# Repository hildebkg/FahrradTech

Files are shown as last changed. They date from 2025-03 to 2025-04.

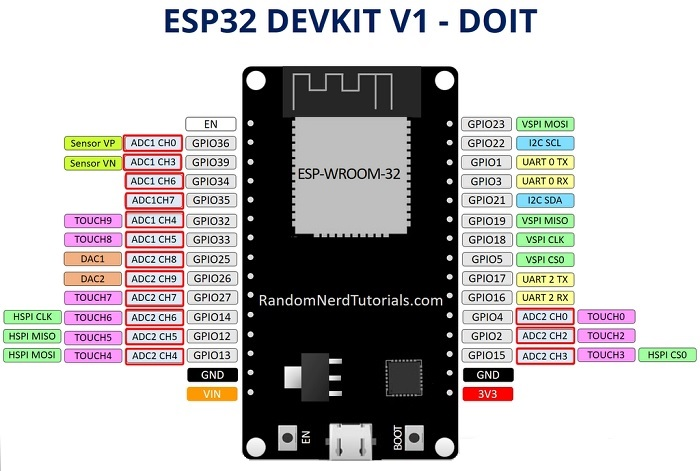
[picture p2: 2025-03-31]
references/esp32_devkitv1_pinout.png

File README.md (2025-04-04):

# FahrradTech

Senior design project files for FahrradTech: an affordable, feature-rich bike computer with integrated safety accessories.

## Navigation

* [/img](/img): project images (referenced throughout this repo)
* [/main](/main): project source code
* [/managed_components](/managed_components/): project libraries
* [/references](/references/): datasheets, etc
* [/schematics](/schematics/): hardware design files
* [/sim](/sim): hardware simulation files

## Getting Started

This project utilizes the official Espressif Systems IoT Development Framework (ESP-IDF). You can view Espressif's official getting started docs [here](https://docs.espressif.com/projects/esp-idf/en/stable/esp32/get-started/index.html). I did a manual installation on Windows 10 (more info on that specifically [here](https://docs.espressif.com/projects/esp-idf/en/stable/esp32/get-started/windows-setup.html)).

* Download the proper installer for your machine (I used “Universal Online Installer 2.3.4” for Windows 10) and run it.
  * I mostly ran with default settings, but I did check the box to install the IDE in case I ever wanted to use it.
* After installation is complete, open a command prompt and run the following commands:
  * `cd C:\Espressif\frameworks\esp-idf-v5.4` (or whatever your install directory is)
  * `install.bat`
    * This installs the ESP-IDF Python virtual environment.
  * `export.bat`
    * This adds ESP-IDF Tools to PATH (not required).
* Keep things simple and get a demo project from [here](https://github.com/espressif/esp-idf/tree/v5.2.5/examples/get-started) or from your install directory (in \examples\get-started). Copy the entire folder to your desired workspace.
* Download the required serial drivers for your board.
  * My board contains a CP2102 USB to UART bridge, but others may differ. If yours has a CP2102, you can download the drivers from Silicon Labs [here](https://www.silabs.com/developer-tools/usb-to-uart-bridge-vcp-drivers?tab=downloads).
* Connect your ESP32 device to your machine and take note of the port to which it is connected. You will need this for the next step. On Windows, this can be checked via the Device Manager.
* To test your chosen example project, fire up either ESP-IDF Cmd or ESP-IDF PowerShell and run the following commands:
  * `cd <dir_containing_example_project>`
  * `idf.py add-dependency esp32`
    * This adds the Board Support Package (BSP) for ESP32 boards. If you have something specific, you can look for it in the [IDF Component Registry](https://components.espressif.com/).
  * `idf.py build`
    * This builds the project. This will take a bit the first time!
  * `idf.py – p COM# flash`
    * This flashes your device with the most recent build.
    * Make sure to replace "COM#" with the port your device is currently using.
  * `idf.py -p COM# monitor`
    * This relays serial data to and from your target device's serial port. This allows you to see output from your board after it has been flashed.
    * More information [here](https://docs.espressif.com/projects/esp-idf/en/stable/esp32/api-guides/tools/idf-monitor.html).
* To add extra components to your project (from within ESP-IDF CMD or PowerShell):
  * `cd <dir_containing_example_project>`
  * `idf.py add-dependency "component_name"`
    * You should replace "component_name" with the name contained in the [IDF Component Registry](https://components.espressif.com/).
  * `idf.py reconfigure`
    * Processes the `idf_component.yml` file in your `main` folder for each component in your project and resolves dependencies.
    * Creates/updates the `dependencies.lock` file in your  project directory with the full dependency list.
    * Downloads all newly-added depedencies to the `managed_components` folder in your project directory.
* If you want to remove a component you have added, you can simply edit the `/main/idf_component.yml` directly. For example, if you added the `espressif/esp_lcd_st7796` component but no longer want it, you can remove that corresponding line in your YAML file and then run `idf.py reconfigure`. You will get a message similar to "NOTICE: Deleting 1 unused components", and the component will be removed for you. Your `dependencies.lock` file will also be updated.
* If you'd like to make development easier in Visual Studio Code with the C/C++ extension, you should add the following to the "include path" setting for the extension: `C:/Espressif/frameworks/esp-idf-v5.4/components/**` (or whatever your specific path is). This will make it so that VS Code can find standard ESP header files that aren't necessarily in your `managed_components folder`.

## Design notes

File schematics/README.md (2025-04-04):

# Hardware Design Files

Schematics and PCB layouts for this project were created in KiCad 8.0.

For convenience, you can view a PDF of each schematic below:

* [Bike computer](bike_computer/bike_computer.pdf)
* [Rear lights unit](rear_lights_unit/rear_lights_unit.pdf)
* [Rear lights unit control box](rear_lights_unit_control_box/rear_lights_unit_control_box.pdf)

Other important components:

* [Symbol library file](FahrradTech.kicad_sym)
* [Footprint files](FahrradTech.pretty/)

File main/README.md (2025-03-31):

# Project Source Code

`main.c` is the main project file and is what is typically built and flashed to the ESP32.

Other .c files in this folder are standalone demonstration files for various components considered for/incorporated in the project. If you want to build one of these instead of the main file, you can modify the `CMakeLists.txt` file in this directory. For example, if you wanted to build `sht3x_demo.c`, you can change the `SRCS` parameter given to `idf_component_register` in the CMake file from `main.c` to `sht3x_demo.c`.

**Note!** I tried a few different parts before I settled on the current design, so some of the demo files here are not applicable to the most recent designs. The following is a list of components that are no longer being used. If you would like to try any of these out, just be sure to add the corresponding component to your project (see root README for more info on this). Doing so will download the necessary files into your managed_components directory.

* [SHT3x temp/humidity sensor](https://components.espressif.com/components/espressif/sht3x/versions/0.2.0)
* [BMP280 pressure sensor](https://components.espressif.com/components/maucke/bmp280/versions/1.0.1)
  * Special note on this one: I had to make several changes to this component library to make it work. Please see my previous commit [here](https://github.com/hildebkg/FarrhadTech/commit/3e463adc17b4526ff7c5bdaee2d7144cd09fb9ec) with the changes if needed.

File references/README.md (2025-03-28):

# References

These are various files that I have downloaded from the internet and referenced in some way for this project. I do not own any of these resources.

(links to be updated)

* [BME280 datasheet](https://web.archive.org/web/20250320165039/https://www.bosch-sensortec.com/media/boschsensortec/downloads/datasheets/bst-bme280-ds002.pdf)
* [Samsung 30Q 18650 battery 1](https://web.archive.org/web/20250228134656/https://www.18650batterystore.com/products/samsung-30q)
* [Samsung 30Q 18650 battery 2](https://web.archive.org/web/20231027183936/https://www.joke-technology.com/media/pdf/c4/9a/9b/datenblatt_inr18650-30q6_cell_specification.pdf)
* [Samsung 30Q 18650 battery study](https://web.archive.org/web/20250219034915/https://lygte-info.dk/review/batteries2012/Samsung%20INR18650-30Q%203000mAh%20(Pink)%20UK.html)

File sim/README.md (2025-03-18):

# Simulation Files

Simulation files for this project were created using National Instruments Multisim version 14.3.

* [Turn signal controls](light_control.ms14)

*Note: KiCad does support SPICE simulation, but I have never used it, and I have heard that the learning curve is steep. I am already used to using Multisim through my university, so I chose to use that for now. There is a free online version which can be accessed [here](https://www.multisim.com/), but they do not currently support importing .MS14 files, so I have added screenshots to this folder for recreation purposes.*

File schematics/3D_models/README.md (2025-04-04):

# 3D Models

KiCad supports adding your own 3D model files on a per-footprint basis. Most of the models in this project are included in the KiCad standard library. I have temporarily borrowed those that weren't via the links below.

* [BME280 sensor module](https://grabcad.com/library/bme280-model-1)
* [ESP-WROOM-32 DevKitV1](https://grabcad.com/library/esp32_devkitv1-1)
* [TP4056 BMS module](https://grabcad.com/library/tp4056-charging-module-type-c-1)

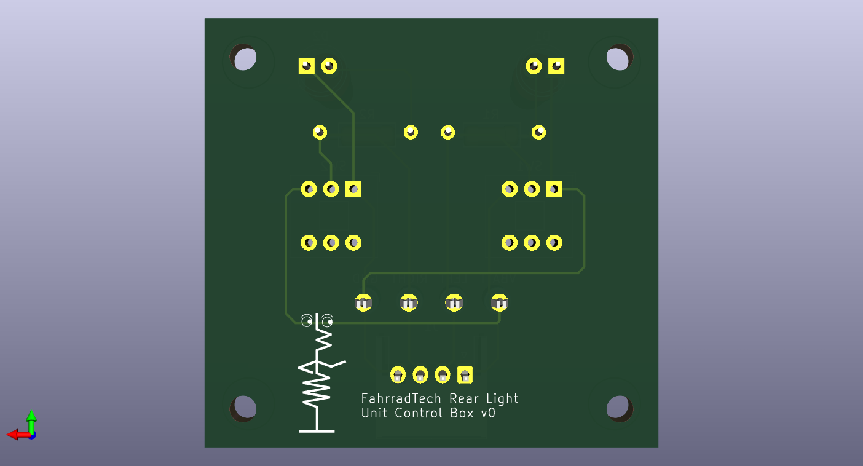
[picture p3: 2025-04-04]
img/rear_lights_unit_control_box_PCB_3D_view_bottom.png

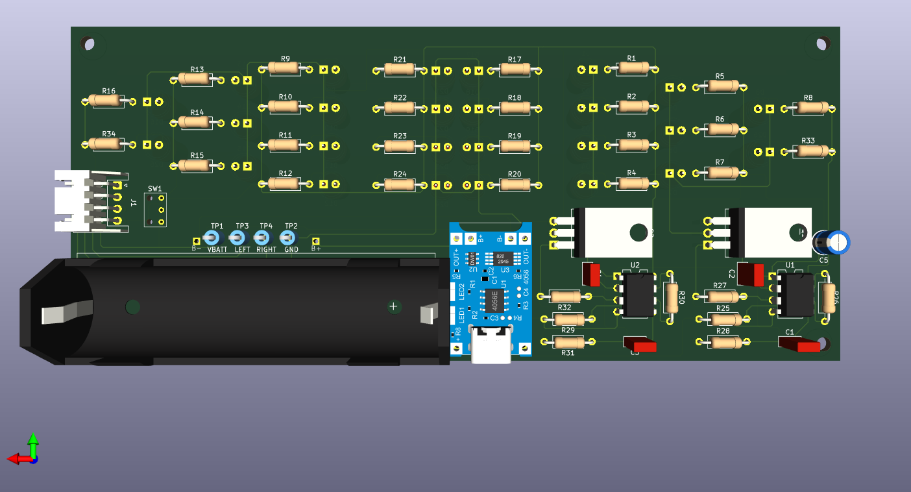
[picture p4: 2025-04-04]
img/rear_lights_unit_PCB_3D_view_bottom.png

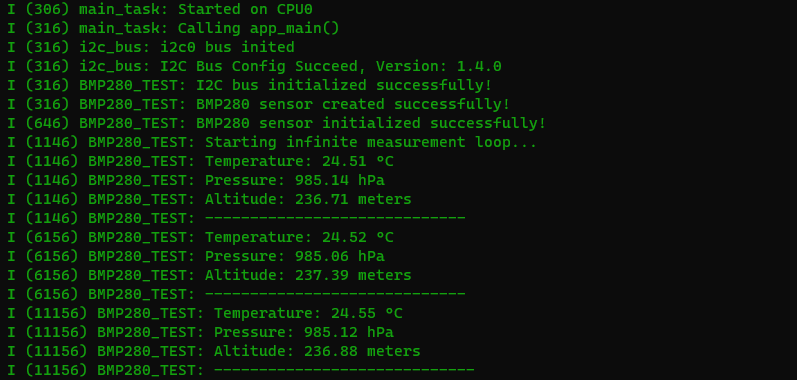
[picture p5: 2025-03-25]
img/BMP_280_demo_sc.png

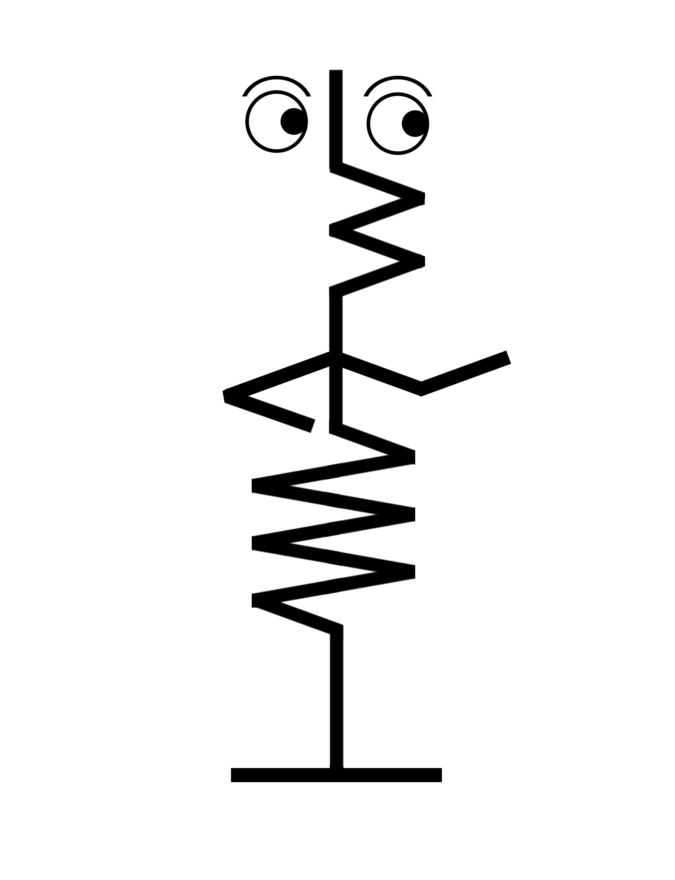
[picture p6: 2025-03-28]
img/RESISTY.png

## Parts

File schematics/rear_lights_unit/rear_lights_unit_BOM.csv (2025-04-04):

Reference | Value | Part Num | Description | Qty | Footprint
BT1 | Battery_Cell | Samsung 30Q 18650 | 18650 battery, 3000 mAH, 3.7 V nominal | 1 | FahrradTech:BatteryHolder_18650
C1,C3 | 0.01uF | K103K15X7RF5TK2 | Unpolarized capacitor, 50 VDC, X7R, 10%, 2.5 mm lead spacing | 2 | Capacitor_THT:C_Rect_L4.6mm_W2.0mm_P2.50mm_MKS02_FKP02
C2,C4 | 10uF | FG18X5R1E106MRT06 | Unpolarized capacitor, 25 VDC, X5R, 20%, 5 mm lead spacing | 2 | Capacitor_THT:C_Rect_L4.6mm_W2.0mm_P2.50mm_MKS02_FKP02
C5 | 10uF | ECA-1EM100 | Polarized capacitor, 25 VDC, 20%, 2mm lead spacing | 1 | Capacitor_THT:CP_Radial_D5.0mm_P2.00mm
D1,D2,D3,D4,D5,D6,D7,D8,D9,D10,D11,D12,D13,D14,D15,D16,D17,D18,D19,D20,D21,D22,D23,D24,D25,D26 | LED | Chanzon LED | Light emitting diode, red or yellow | 26 | LED_THT:LED_D5.0mm
J1 | Conn_01x04_Socket | JST XH-2.54 | Generic connector, single row, 01x04, script generated | 1 | Connector_JST:JST_XH_S4B-XH-A_1x04_P2.50mm_Horizontal
Q1,Q2 | IRLZ44N | IRLZ44N | 47A Id, 55V Vds, 22mOhm Rds Single N-Channel HEXFET Power MOSFET, TO-220AB | 2 | FahrradTech:TO-220-3_Horizontal_TabUpNoHole
R1,R2,R3,R4,R5,R6,R7,R8,R9,R10,R11,R12,R13,R14,R15,R16,R17,R18,R19,R20,R21,R22,R23,R24,R33,R34 | 120 | MFR-25SFTF52-120R | Resistor, 0.25 W, 1% | 26 | Resistor_THT:R_Axial_DIN0207_L6.3mm_D2.5mm_P10.16mm_Horizontal
R25,R29 | 7.5k | MFR-25FTE52-7K5 | Resistor, 0.25 W, 1% | 2 | Resistor_THT:R_Axial_DIN0207_L6.3mm_D2.5mm_P10.16mm_Horizontal
R26,R30 | 75k | MFR-25FTE52-75K | Resistor, 0.25 W, 1% | 2 | Resistor_THT:R_Axial_DIN0207_L6.3mm_D2.5mm_P10.16mm_Horizontal
R27,R32 | 100 | MFR-25SFTF52-100R | Resistor, 0.25 W, 1% | 2 | Resistor_THT:R_Axial_DIN0207_L6.3mm_D2.5mm_P10.16mm_Horizontal
R28,R31 | 10k | MFR-25SFRF52-10K | Resistor, 0.25 W, 1% | 2 | Resistor_THT:R_Axial_DIN0207_L6.3mm_D2.5mm_P10.16mm_Horizontal
SW1 | GW12LxH | GW12LCH | SPDT paddle switch, red, right-angle | 1 | FahrradTech:SW_Lever_1P2T_NKK_GW12LxH
TP1 | VBATT | Keystone Electronics 5000 | Test point loop, red | 1 | FahrradTech:TestPoint_Keystone_5000-5004_Miniature
TP2 | GND | Keystone Electronics 5002 | Test point loop, black | 1 | FahrradTech:TestPoint_Keystone_5000-5004_Miniature
TP3 | LEFT | Keystone Electronics 5001 | Test point loop, white | 1 | FahrradTech:TestPoint_Keystone_5000-5004_Miniature
TP4 | RIGHT | Keystone Electronics 5001 | Test point loop, white | 1 | FahrradTech:TestPoint_Keystone_5000-5004_Miniature
U1,U2 | LMC555xN | LMC555CN/NOPB | CMOS Timer, 555 compatible, PDIP-8 | 2 | Package_DIP:DIP-8_W7.62mm
U3 | TP4056 module | TP4056 module | 18650 battery management module | 1 | FahrradTech:TP4056_module

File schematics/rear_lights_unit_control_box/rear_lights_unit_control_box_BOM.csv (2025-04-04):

Reference | Value | Part Num | Description | Qty | Footprint
D1,D2 | LED | CHANZON 5mm LED | Light emitting diode, yellow | 2 | LED_THT:LED_D5.0mm
J1 | Conn_01x04_Socket | JST XH-2.54 | 01x04 pin JST right-angle connector | 1 | Connector_JST:JST_XH_S4B-XH-A-1_1x04_P2.50mm_Horizontal
R1,R2 | 120 | MFR-25SFTF52-120R | Resistor, 0.25 W, 1% | 2 | Resistor_THT:R_Axial_DIN0207_L6.3mm_D2.5mm_P10.16mm_Horizontal
SW1,SW2 | SW_SPDT | SPDT SW | Switch, single pole double throw | 2 | Button_Switch_THT:SW_Push_2P2T_Toggle_CK_PVA2xxH2xxxxxxV2
TP1 | VBATT | Keystone Electronics 5000 | Test point loop, red | 1 | FahrradTech:TestPoint_Keystone_5000-5004_Miniature
TP2 | LEFT | Keystone Electronics 5001 | Test point loop, white | 1 | FahrradTech:TestPoint_Keystone_5000-5004_Miniature
TP3 | RIGHT | Keystone Electronics 5001 | Test point loop, white | 1 | FahrradTech:TestPoint_Keystone_5000-5004_Miniature
TP4 | GND | Keystone Electronics 5002 | Test point loop, black | 1 | FahrradTech:TestPoint_Keystone_5000-5004_Miniature

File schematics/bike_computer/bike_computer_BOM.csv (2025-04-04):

Reference | Value | Part Num | Description | Qty | Footprint
BT1 | Battery_Cell | Samsung 30Q 18650 | 18650 battery, 3000 mAH, 3.7 V nominal | 1 | FarrhadTech:BatteryHolder_18650
C1,C4,C5,C6 | 0.1uF | FG18X7R1H104KNT00 | Unpolarized capacitor, 50 VDC, X7R, 10%, 2.5 mm lead spacing | 4 | Capacitor_THT:C_Rect_L4.6mm_W2.0mm_P2.50mm_MKS02_FKP02
C2 | 470pF | K471K15X7RF53L2 | Unpolarized capacitor, 50 VDC, X7R, 10%, 2.5 mm lead spacing | 1 | Capacitor_THT:C_Rect_L4.6mm_W2.0mm_P2.50mm_MKS02_FKP02
C3,C7 | 10uF | ECA-1EM100 | Polarized capacitor, 25 VDC, 20%, 2mm lead spacing | 2 | Capacitor_THT:CP_Radial_D5.0mm_P2.00mm
R1 | 121k | MFR-25FBF52-121K | Resistor, 0.25 W, 1% | 1 | Resistor_THT:R_Axial_DIN0207_L6.3mm_D2.5mm_P10.16mm_Horizontal
R2 | 40.2k | MFR-25FTE52-40K2 | Resistor, 0.25 W, 1% | 1 | Resistor_THT:R_Axial_DIN0207_L6.3mm_D2.5mm_P10.16mm_Horizontal
SW1 | GW12LxH | GW12LxH | SPDT paddle switch, red, right-angle | 1 | FarrhadTech:SW_Lever_1P2T_NKK_GW12LxH
TP1 | VBATT | Keystone Electronics 5000 | Test point loop, red | 1 | FarrhadTech:TestPoint_Keystone_5000-5004_Miniature
TP2 | GND | Keystone Electronics 5002 | Test point loop, black | 1 | FarrhadTech:TestPoint_Keystone_5000-5004_Miniature
TP3 | 3V3 | Keystone Electronics 5000 | Test point loop, red | 1 | FarrhadTech:TestPoint_Keystone_5000-5004_Miniature
U2 | BME280 | BME280 module | 3-in-1 sensor, humidity, pressure, temperature, I2C and SPI interface, 1.71-3.6V | 1 | FarrhadTech:BME280_module
U3 | TC1263 | TC1263-3.3VAT | 3.3 V Fixed-Output CMOS LDO | 1 | FarrhadTech:TO-220-5_P3.4x3.8mm_StaggerOdd_Lead7.13mm_TabDown
U4 | TFT LCD ST7796 | Hosyond TFT LCD 480x320 | 480x320 TFT Touch Screen LCD | 1 | FarrhadTech:Display_420x380
U5 | TP4056 module | TP4056 module | 18650 battery management module | 1 | FarrhadTech:TP4056_module
U6 | RYS352A | REYAX RYS352A | UART GNSS antenna module | 1 | FarrhadTech:RYS352A
U7 | ESP-WROOM-32-DevKitV1 | ESP-WROOM-32-DevKitV1 | RF Module, ESP32-D0WDQ6 SoC, Wi-Fi 802.11b/g/n, Bluetooth, BLE, 32-bit, 2.7-3.6V, onboard antenna, SMD | 1 | FarrhadTech:ESP-WROOM-32_DevKitV1

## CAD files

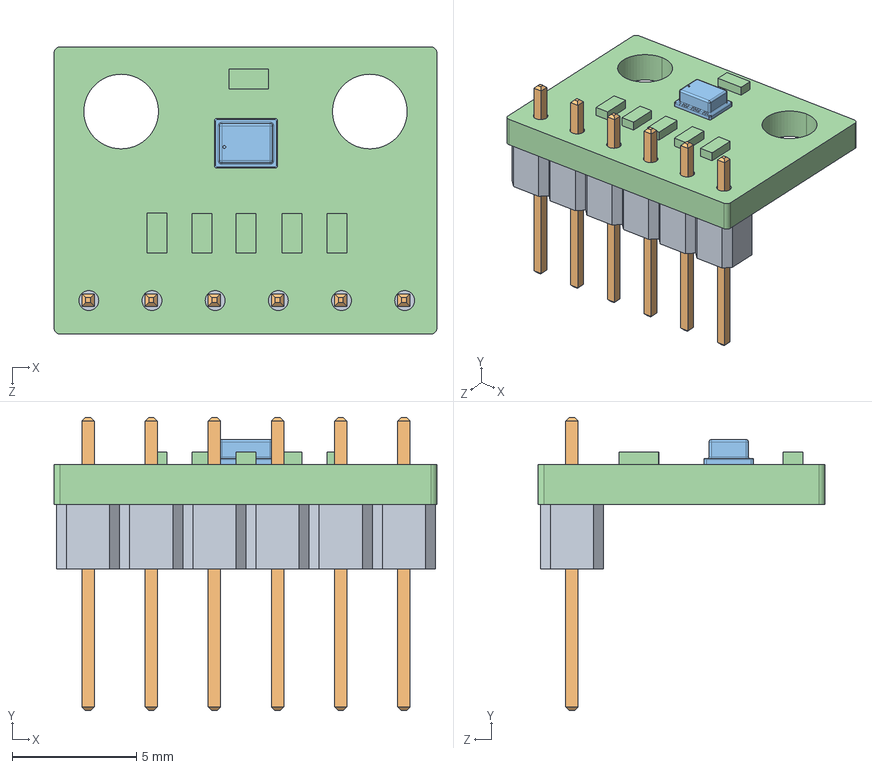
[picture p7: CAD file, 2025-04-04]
schematics/3D_models/BME280_SENSOR_MODULE_WITH_HEADER.STEP
15.4 x 11.8 x 11.6 mm

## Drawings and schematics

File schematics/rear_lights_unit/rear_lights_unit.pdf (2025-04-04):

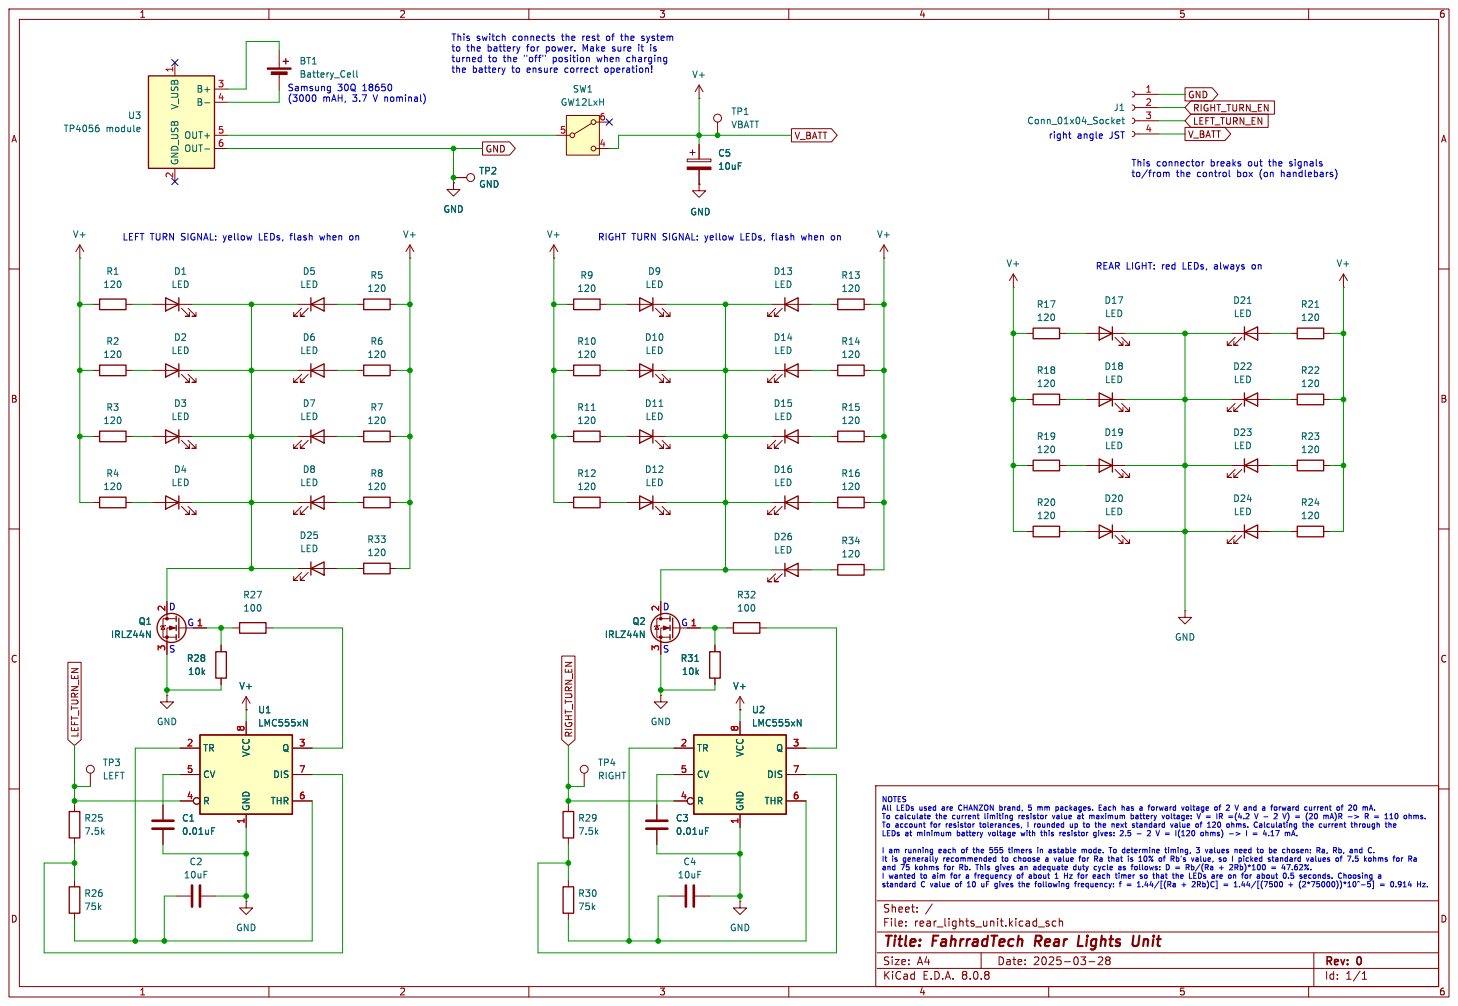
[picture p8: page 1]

to the battery for power. Make sure it is

the battery to ensure correct operation! G

right angle JST Samsung 30Q 18650

RIGHT TURN SIGNAL: yellow LEDs, flash when on D

Id: 1/1 Title: FahrradTech Rear Lights Unit File: rear_lights_unit.kicad_sch Sheet: /

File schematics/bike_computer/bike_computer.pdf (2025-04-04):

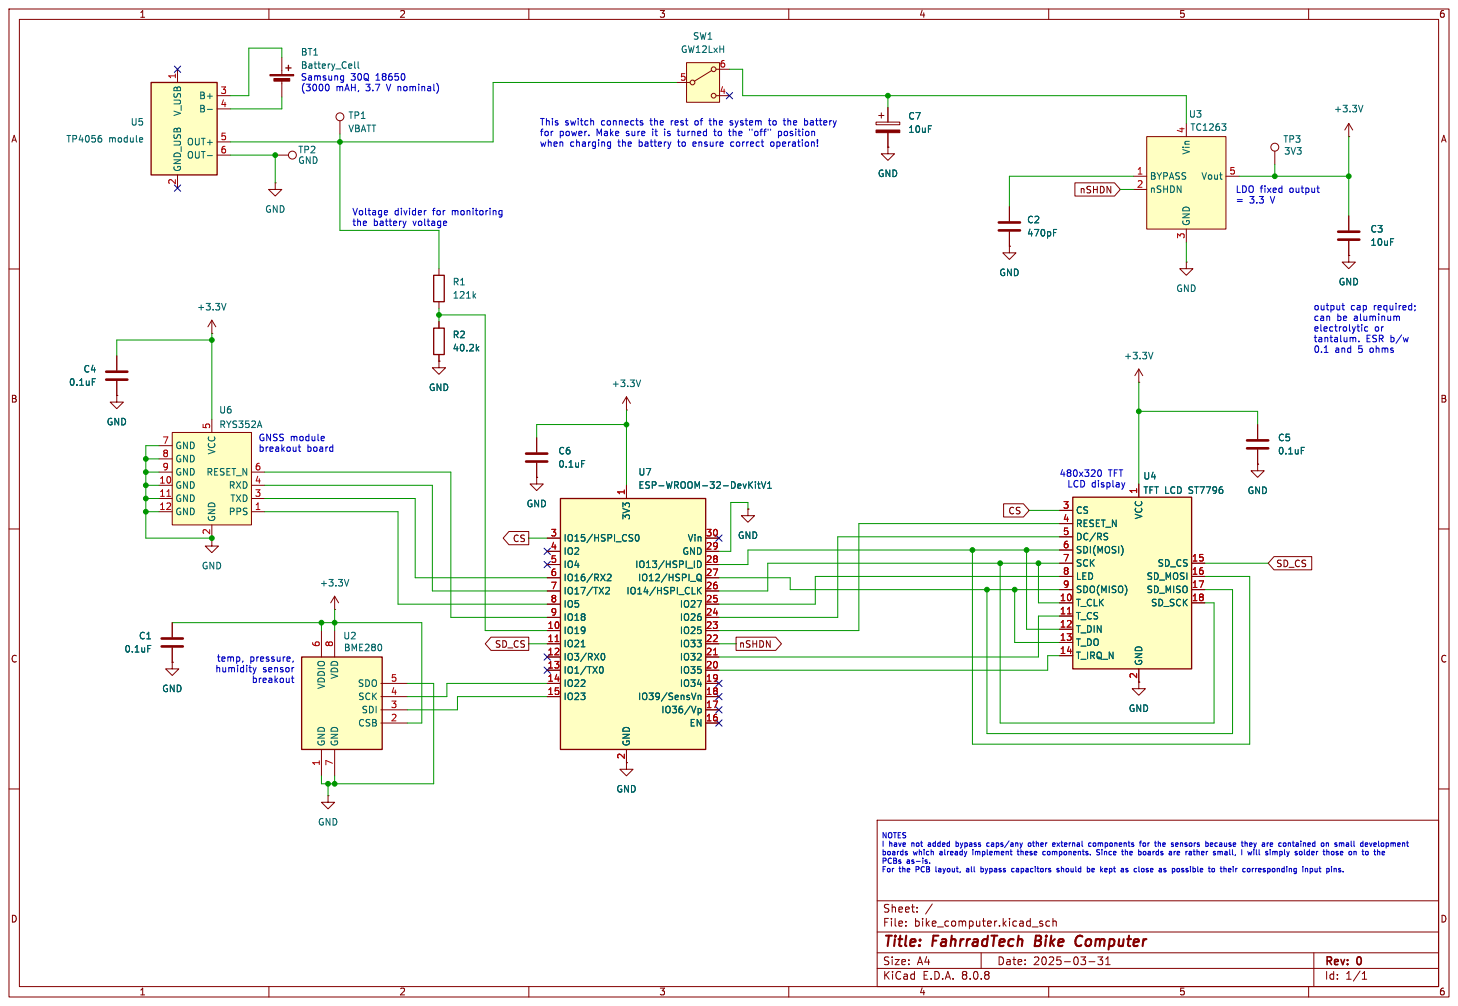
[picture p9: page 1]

1 GND_USB
Id: 1/1 Title: FahrradTech Bike Computer File: bike_computer.kicad_sch Sheet: / V_USB

2 B+ 3 B- 4 OUT+ 5 OUT- 6 U5 TP4056 module GND

0.1 and 5 ohms LDO fixed output = 3.3 V

Voltage divider for monitoring
the battery voltage

output cap required; can be aluminum

2 CS 3 RESET_N 4 DC/RS 5 SDI(MOSI) 6 SCK 7

1 CSB 2 SDI 3 SCK 4 SDO 5 VDDIO

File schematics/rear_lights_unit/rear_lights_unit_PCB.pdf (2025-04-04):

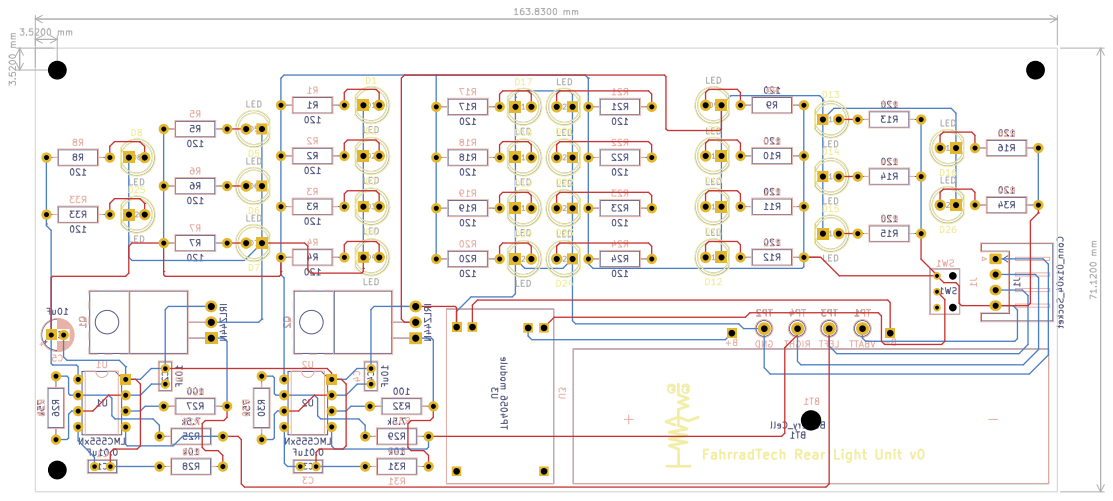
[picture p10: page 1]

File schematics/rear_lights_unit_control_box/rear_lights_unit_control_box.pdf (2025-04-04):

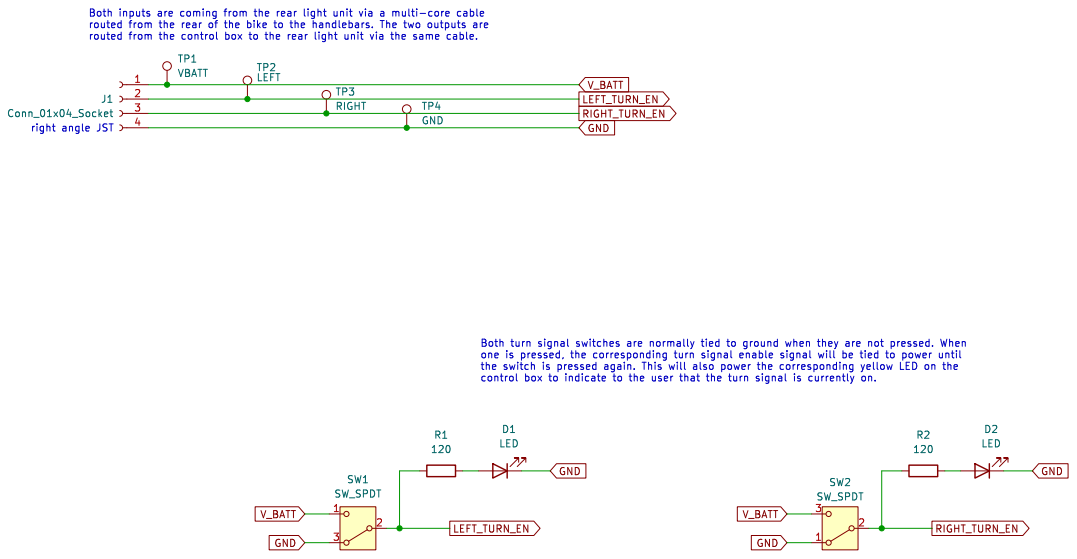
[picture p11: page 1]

Id: 1/1 Title: FahrradTech Rear Lights Unit Control Box

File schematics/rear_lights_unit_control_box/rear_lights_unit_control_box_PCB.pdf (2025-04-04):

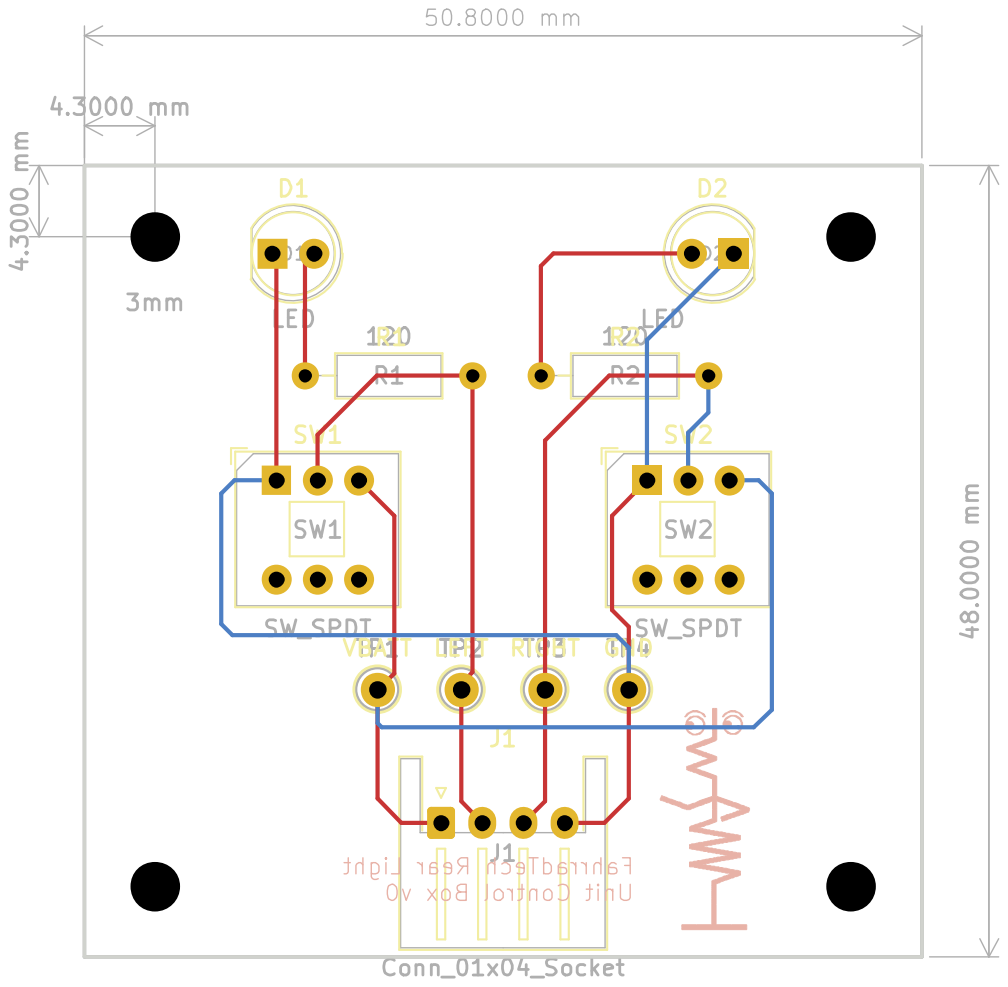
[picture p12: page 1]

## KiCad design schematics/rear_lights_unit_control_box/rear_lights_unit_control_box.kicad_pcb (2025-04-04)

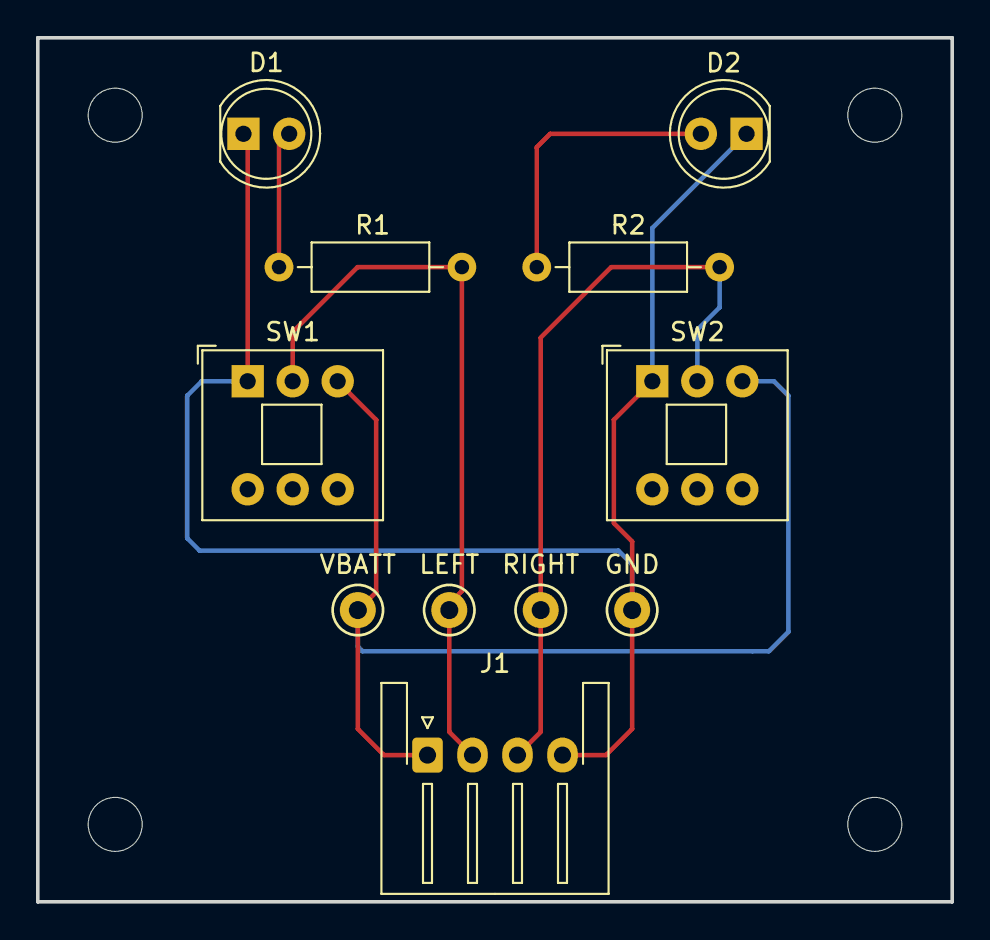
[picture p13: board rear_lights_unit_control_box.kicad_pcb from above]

Board: 2 copper layers, 50.8 x 48.0 mm, 11 parts (0 on the bottom side), 6 nets.

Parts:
D1, D2: LED; LED_D5.0mm
J1: Conn_01x04_Socket; JST_XH_S4B-XH-A-1_1x04_P2.50mm_Horizontal
R1, R2: 120; R_Axial_DIN0207_L6.3mm_D2.5mm_P10.16mm_Horizontal
SW1, SW2: SW_SPDT; SW_Push_2P2T_Toggle_CK_PVA2xxH2xxxxxxV2
TP1: VBATT; TestPoint_Keystone_5000-5004_Miniature
TP2: LEFT; TestPoint_Keystone_5000-5004_Miniature
TP3: RIGHT; TestPoint_Keystone_5000-5004_Miniature
TP4: GND; TestPoint_Keystone_5000-5004_Miniature

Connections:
GND: D1.1 (K), D2.1 (K), J1.4, SW1.1 (A), SW2.1 (A), TP4.1
LEFT_TURN_EN: J1.2, R1.1, SW1.2 (B), TP2.1
unnamed: D1.2 (A), R1.2
unnamed: D2.2 (A), R2.2
RIGHT_TURN_EN: J1.3, R2.1, SW2.2 (B), TP3.1
V_OUT: J1.1, SW1.3 (C), SW2.3 (C), TP1.1

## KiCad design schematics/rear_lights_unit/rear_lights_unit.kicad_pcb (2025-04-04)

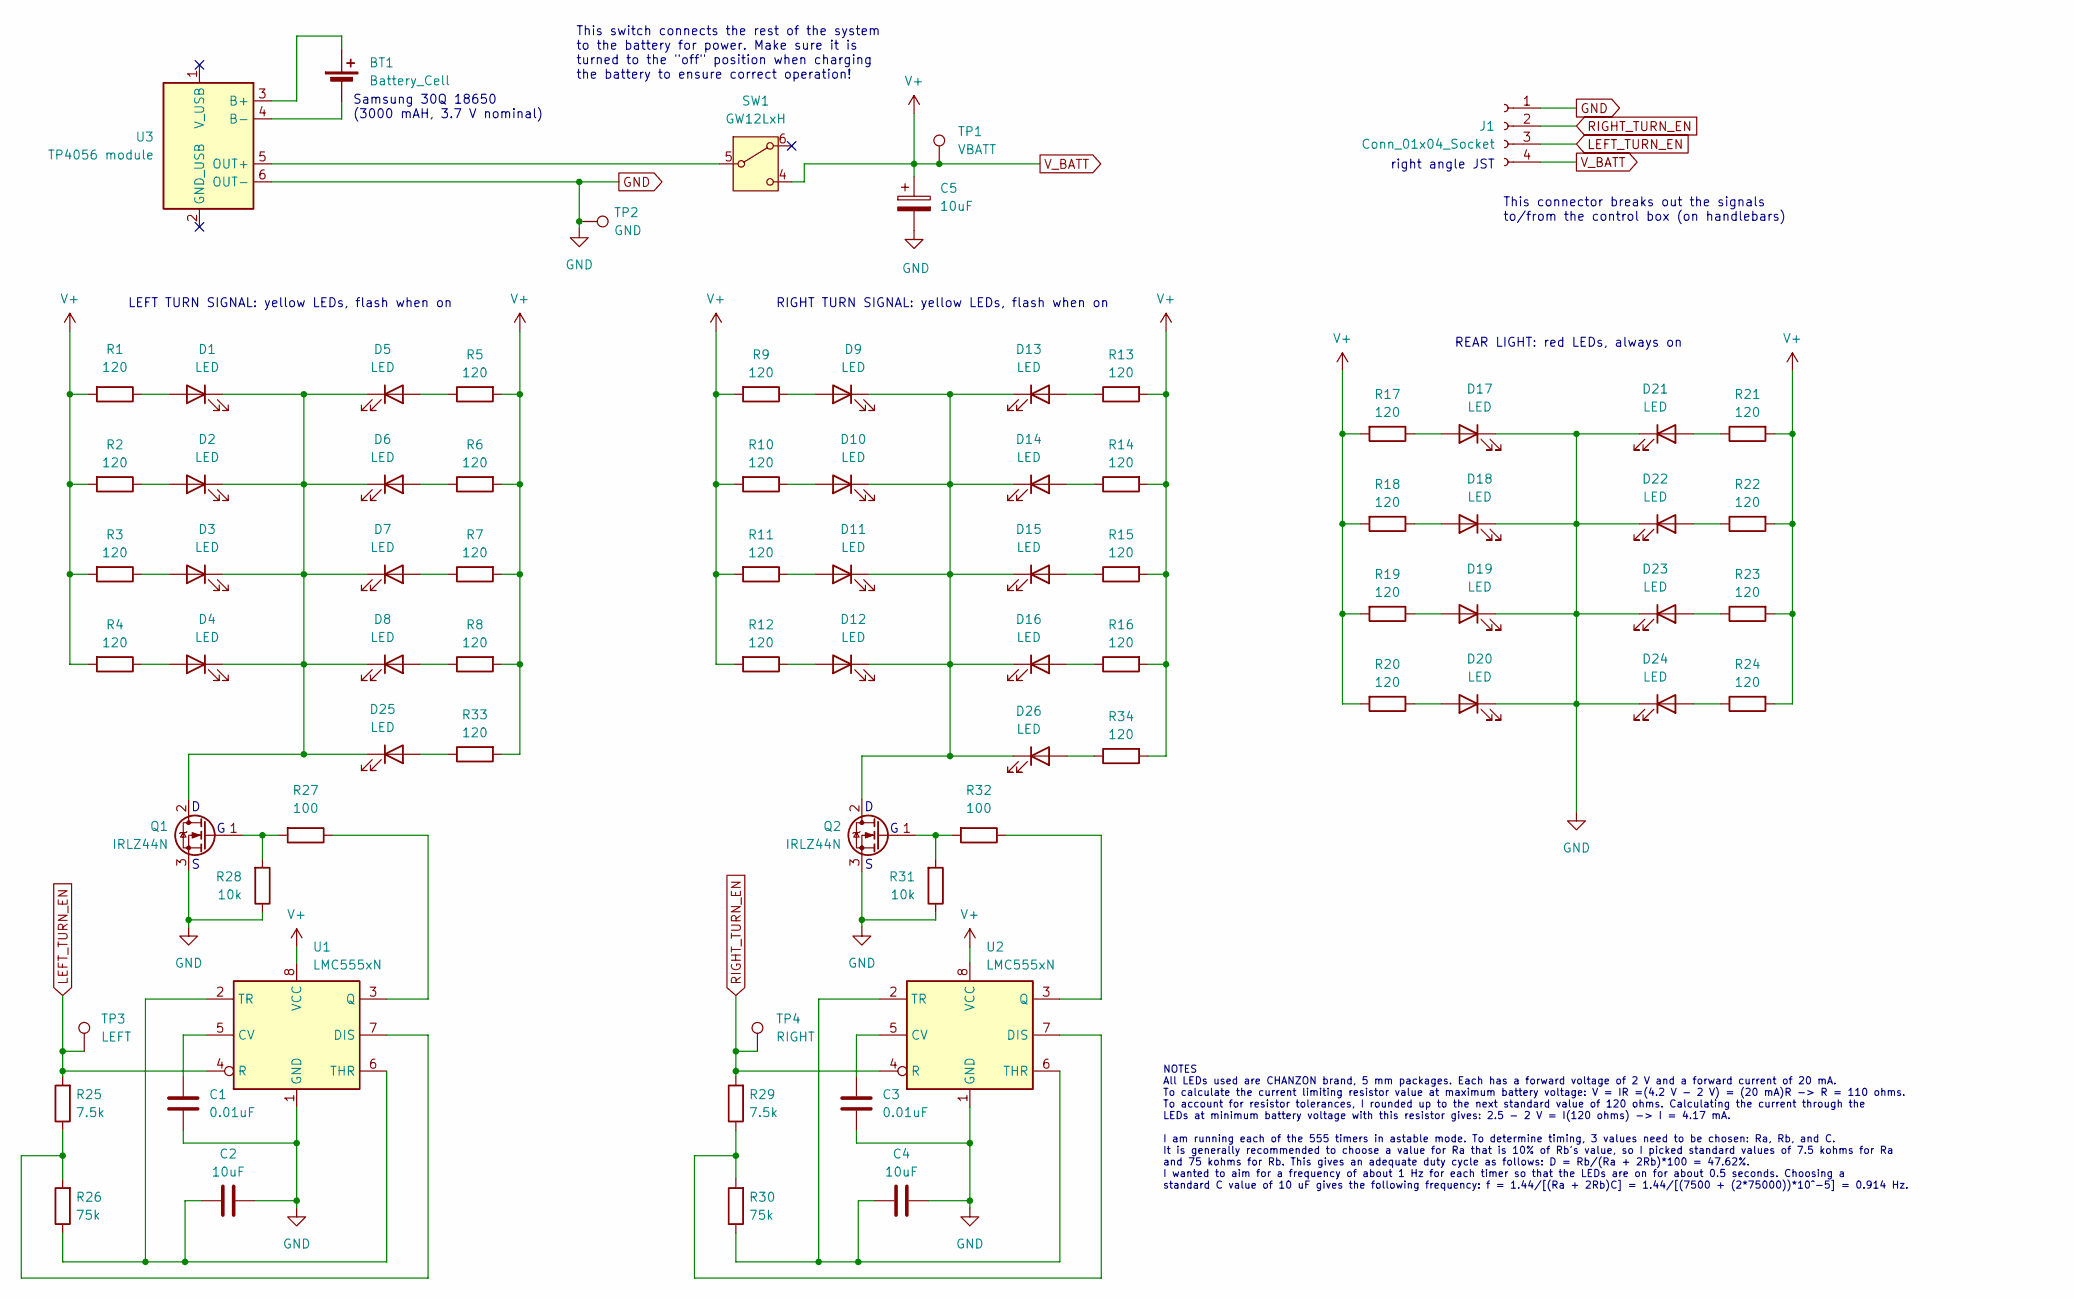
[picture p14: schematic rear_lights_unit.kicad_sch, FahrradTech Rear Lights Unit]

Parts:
BT1: Battery_Cell; BatteryHolder_18650; Part Num Samsung 30Q 18650
C1, C3: 0.01uF; C_Rect_L4.6mm_W2.0mm_P2.50mm_MKS02_FKP02; Part Num K103K15X7RF5TK2
C2, C4: 10uF; C_Rect_L4.6mm_W2.0mm_P2.50mm_MKS02_FKP02; Part Num FG18X5R1E106MRT06
C5: 10uF; CP_Radial_D5.0mm_P2.00mm; Part Num ECA-1EM100
D1, D2, D3, D4, D5, D6, D7, D8, D9, D10, D11, D12, D13, D14, D15, D16, D17, D18, D19, D20, D21, D22, D23, D24, D25, D26: LED; LED_D5.0mm; Part Num Chanzon LED
J1: Conn_01x04_Socket; JST_XH_S4B-XH-A_1x04_P2.50mm_Horizontal; Part Num JST XH-2.54
Q1, Q2: IRLZ44N; TO-220-3_Horizontal_TabUpNoHole; Part Num IRLZ44N
R1, R2, R3, R4, R5, R6, R7, R8, R9, R10, R11, R12, R13, R14, R15, R16, R17, R18, R19, R20, R21, R22, R23, R24, R33, R34: 120; R_Axial_DIN0207_L6.3mm_D2.5mm_P10.16mm_Horizontal; Part Num MFR-25SFTF52-120R
R25, R29: 7.5k; R_Axial_DIN0207_L6.3mm_D2.5mm_P10.16mm_Horizontal; Part Num MFR-25FTE52-7K5
R26, R30: 75k; R_Axial_DIN0207_L6.3mm_D2.5mm_P10.16mm_Horizontal; Part Num MFR-25FTE52-75K
R27, R32: 100; R_Axial_DIN0207_L6.3mm_D2.5mm_P10.16mm_Horizontal; Part Num MFR-25SFTF52-100R
R28, R31: 10k; R_Axial_DIN0207_L6.3mm_D2.5mm_P10.16mm_Horizontal; Part Num MFR-25SFRF52-10K
SW1: GW12LxH; SW_Lever_1P2T_NKK_GW12LxH; Part Num GW12LCH
TP1: VBATT; TestPoint_Keystone_5000-5004_Miniature; Part Num Keystone Electronics 5000
TP2: GND; TestPoint_Keystone_5000-5004_Miniature; Part Num Keystone Electronics 5002
TP3: LEFT; TestPoint_Keystone_5000-5004_Miniature; Part Num Keystone Electronics 5001
TP4: RIGHT; TestPoint_Keystone_5000-5004_Miniature; Part Num Keystone Electronics 5001
U1, U2: LMC555xN; DIP-8_W7.62mm; Part Num LMC555CN/NOPB
U3: TP4056 module; TP4056_module; Part Num TP4056 module

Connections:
GND: C1.2, C2.1, C3.2, C4.1, C5.2, D17.1 (K), D18.1 (K), D19.1 (K), D20.1 (K), D21.1 (K), D22.1 (K), D23.1 (K), D24.1 (K), J1.1, Q1.3 (S), Q2.3 (S), R28.1, R31.1, TP2.1, U1.1 (GND), U2.1 (GND), U3.6 (OUT-)
LEFT_TURN_EN: J1.3, R25.2, TP3.1, U1.4 (R)
unnamed: BT1.1 (+), U3.3 (B+)
unnamed: BT1.2 (-), U3.4 (B-)
unnamed: D1.2 (A), R1.1
unnamed: D1.1 (K), D2.1 (K), D3.1 (K), D4.1 (K), D5.1 (K), D6.1 (K), D7.1 (K), D8.1 (K), D25.1 (K), Q1.2 (D)
unnamed: D2.2 (A), R2.1
unnamed: D3.2 (A), R3.1
unnamed: D4.2 (A), R4.1
unnamed: D5.2 (A), R5.1
unnamed: D6.2 (A), R6.1
unnamed: D7.2 (A), R7.1
unnamed: D8.2 (A), R8.1
unnamed: D9.2 (A), R9.1
unnamed: D10.2 (A), R10.1
unnamed: D9.1 (K), D10.1 (K), D11.1 (K), D12.1 (K), D13.1 (K), D14.1 (K), D15.1 (K), D16.1 (K), D26.1 (K), Q2.2 (D)
unnamed: D11.2 (A), R11.1
unnamed: D12.2 (A), R12.1
unnamed: D13.2 (A), R13.1
unnamed: D14.2 (A), R14.1
unnamed: D15.2 (A), R15.1
unnamed: D16.2 (A), R16.1
unnamed: D17.2 (A), R17.1
unnamed: D18.2 (A), R18.1
unnamed: D19.2 (A), R19.1
unnamed: D20.2 (A), R20.1
unnamed: D21.2 (A), R21.1
unnamed: D22.2 (A), R22.1
unnamed: D23.2 (A), R23.1
unnamed: D24.2 (A), R24.1
unnamed: D25.2 (A), R33.1
unnamed: D26.2 (A), R34.1
unnamed: Q1.1 (G), R27.2, R28.2
unnamed: Q2.1 (G), R31.2, R32.2
unnamed: C1.1, U1.5 (CV)
unnamed: R25.1, R26.2, U1.7 (DIS)
unnamed: R27.1, U1.3 (Q)
unnamed: C2.2, R26.1, U1.2 (TR), U1.6 (THR)
unnamed: C3.1, U2.5 (CV)
unnamed: R29.1, R30.2, U2.7 (DIS)
unnamed: R32.1, U2.3 (Q)
unnamed: C4.2, R30.1, U2.2 (TR), U2.6 (THR)
unnamed: SW1.5, U3.5 (OUT+)
RIGHT_TURN_EN: J1.2, R29.2, TP4.1, U2.4 (R)
V_BATT: C5.1, J1.4, R1.2, R2.2, R3.2, R4.2, R5.2, R6.2, R7.2, R8.2, R9.2, R10.2, R11.2, R12.2, R13.2, R14.2, R15.2, R16.2, R17.2, R18.2, R19.2, R20.2, R21.2, R22.2, R23.2, R24.2, R33.2, R34.2, SW1.4, TP1.1, U1.8 (VCC), U2.8 (VCC)

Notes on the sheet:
REAR LIGHT: red LEDs, always on
This connector breaks out the signals to/from the control box (on handlebars)
This switch connects the rest of the system to the battery for power. Make sure it is turned to the "off" position when charging the battery to ensure correct operation!
right angle JST
Samsung 30Q 18650 (3000 mAH, 3.7 V nominal)
LEFT TURN SIGNAL: yellow LEDs, flash when on
RIGHT TURN SIGNAL: yellow LEDs, flash when on
NOTES All LEDs used are CHANZON brand, 5 mm packages. Each has a forward voltage of 2 V and a forward current of 20 mA. To calculate the current limiting resistor value at maximum battery voltage: V = IR =(4.2 V - 2 V) = (20 mA)R -> R = 110 ohms. To account for resistor tolerances, I rounded up to 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

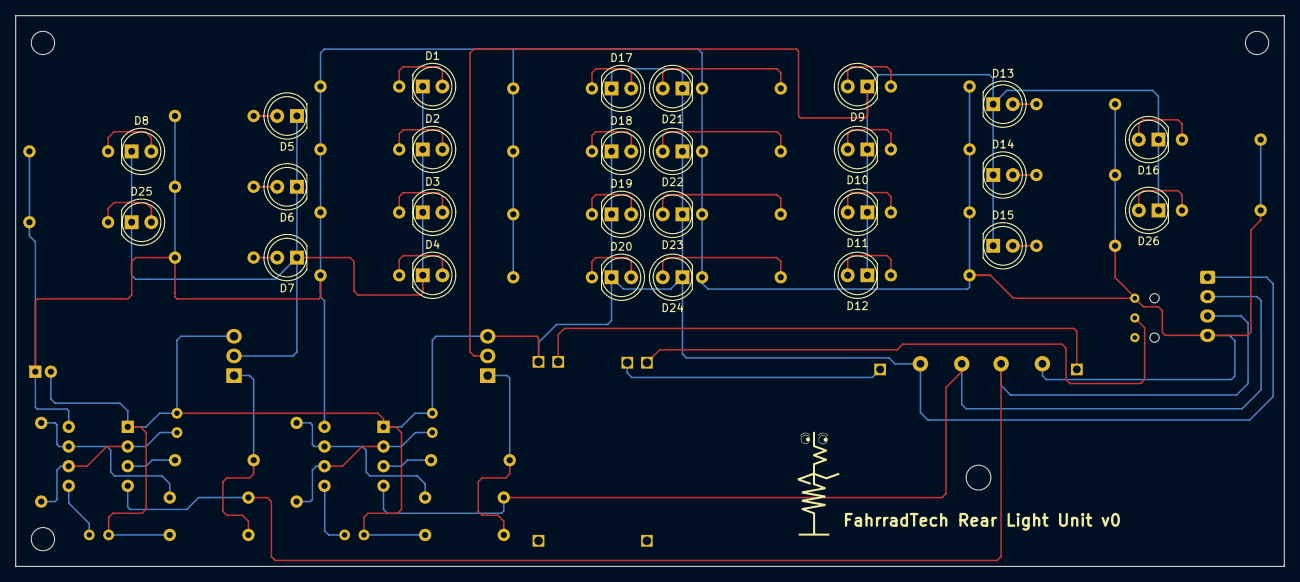
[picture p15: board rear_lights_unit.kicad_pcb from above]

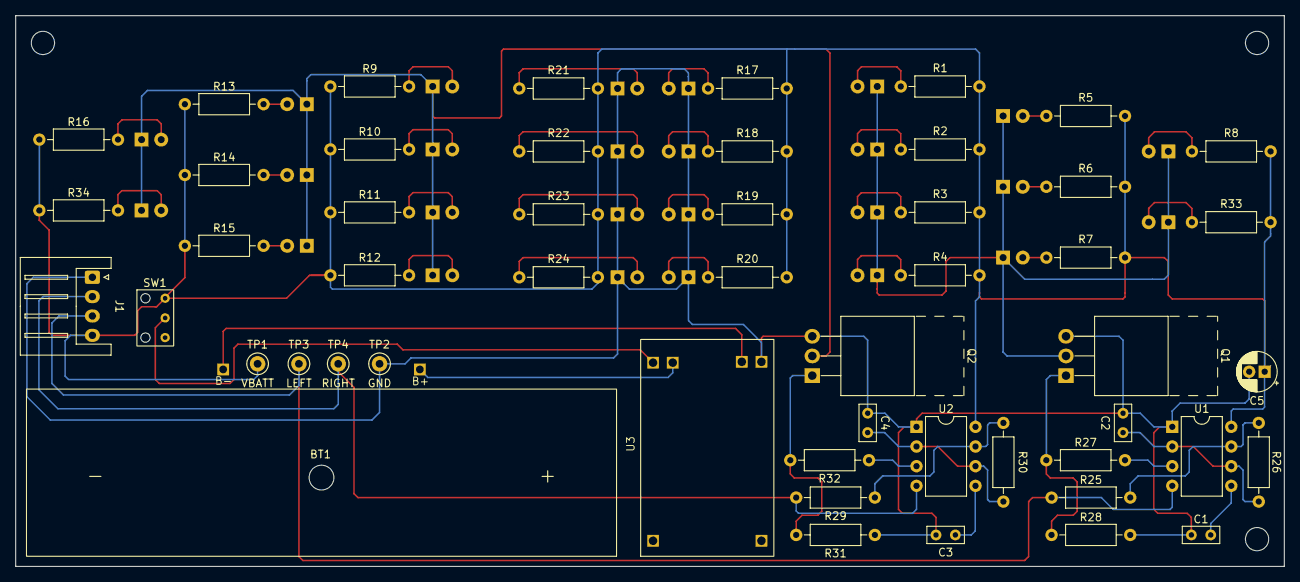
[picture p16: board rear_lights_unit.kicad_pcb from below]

Board: 2 copper layers, 163.8 x 71.1 mm, 77 parts (51 on the bottom side), 45 nets.

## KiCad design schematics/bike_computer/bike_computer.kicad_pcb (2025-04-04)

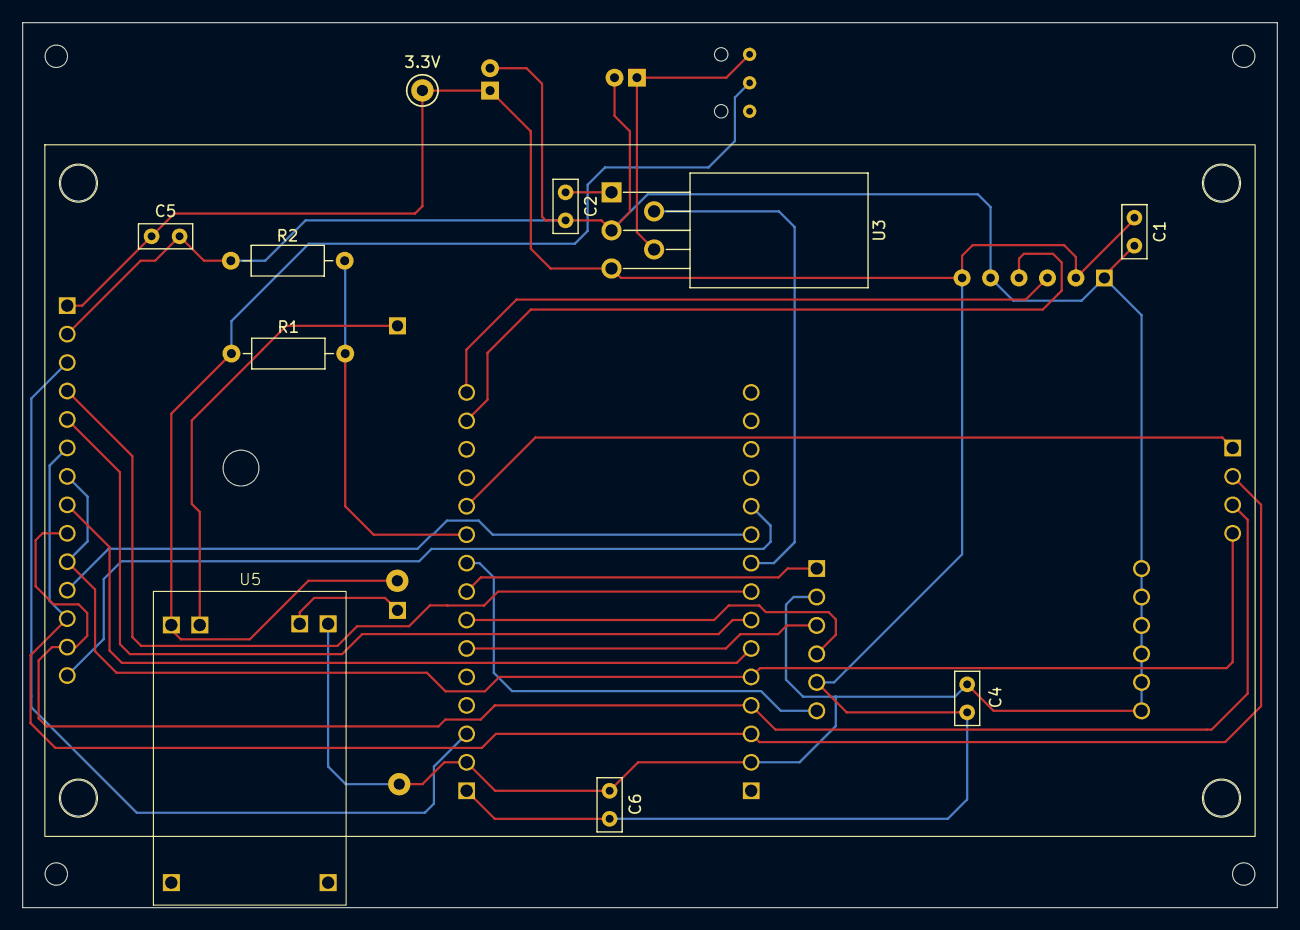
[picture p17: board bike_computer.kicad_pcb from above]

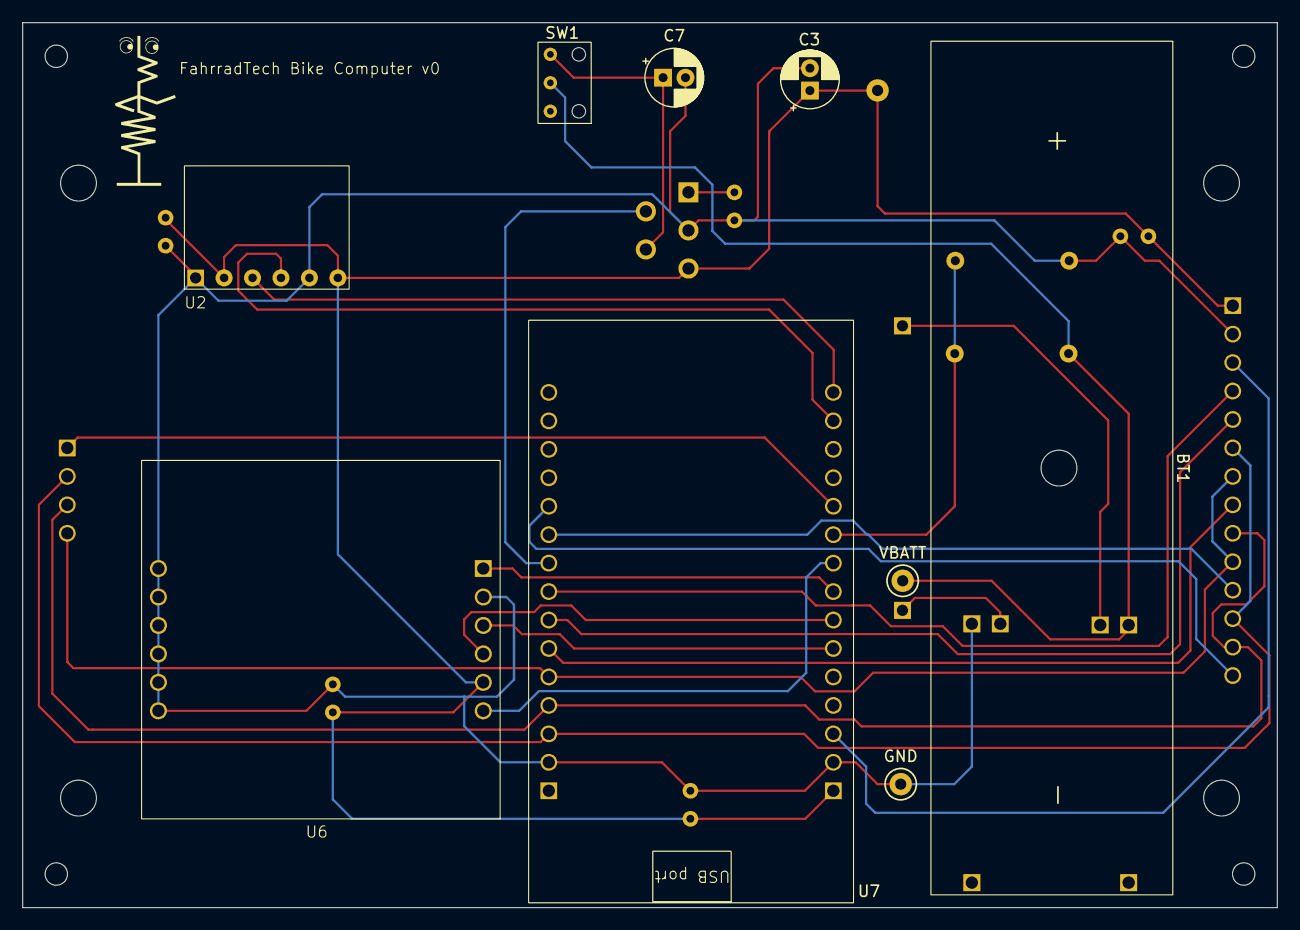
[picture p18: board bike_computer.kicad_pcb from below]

Board: 2 copper layers, 112.0 x 79.0 mm, 20 parts (9 on the bottom side), 25 nets.

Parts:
3.3V: 3V3; TestPoint_Keystone_5000-5004_Miniature
BT1: Battery_Cell; BatteryHolder_18650
C1, C4, C5, C6: 0.1uF; C_Rect_L4.6mm_W2.0mm_P2.50mm_MKS02_FKP02
C2: 470pF; C_Rect_L4.6mm_W2.0mm_P2.50mm_MKS02_FKP02
C3, C7: 10uF; CP_Radial_D5.0mm_P2.00mm
GND: GND; TestPoint_Keystone_5000-5004_Miniature
R1: 121k; R_Axial_DIN0207_L6.3mm_D2.5mm_P10.16mm_Horizontal
R2: 40.2k; R_Axial_DIN0207_L6.3mm_D2.5mm_P10.16mm_Horizontal
SW1: GW12LxH; SW_Lever_1P2T_NKK_GW12LxH
U2: BME280; BME280_module
U3: TC1263; TO-220-5_P3.4x3.8mm_StaggerOdd_Lead7.13mm_TabDown
U4: TFT LCD ST7796; Display_420x380
U5: TP4056 module; TP4056_module
U6: RYS352A
U7: ESP-WROOM-32-DevKitV1; ESP-WROOM-32_DevKitV1
VBATT: VBATT; TestPoint_Keystone_5000-5004_Miniature

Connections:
+3.3V: 3.3V.1, C1.1, C3.1, C4.1, C5.1, C6.1, U2.2 (CSB), U2.6 (VDDIO), U3.5 (Vout), U4.1 (VCC), U6.5 (VCC), U7.1 (3V3)
CS: U4.3 (CS), U7.3 (IO15/HSPI_CS0)
GND: C1.2, C2.2, C3.2, C4.2, C5.2, C6.2, C7.2, GND.1, R2.2, U2.1 (GND), U2.5 (SDO), U3.3 (GND), U4.2 (GND), U5.6 (OUT-), U6.2 (GND), U6.7 (GND), U6.8 (GND), U6.9 (GND), U6.10 (GND), U6.11 (GND), U6.12 (GND), U7.2 (GND), U7.29 (GND)
unnamed: BT1.1 (+), U5.3 (B+)
unnamed: BT1.2 (-), U5.4 (B-)
unnamed: U2.4 (SCK), U7.14 (IO22)
unnamed: U2.3 (SDI), U7.15 (IO23)
unnamed: C2.1, U3.1 (BYPASS)
unnamed: C7.1, SW1.6, U3.4 (Vin)
unnamed: U4.5 (DC/RS), U7.24 (IO26)
unnamed: U4.8 (LED), U7.25 (IO27)
unnamed: U4.4 (RESET_N), U7.23 (IO25)
unnamed: U4.7 (SCK), U4.10 (T_CLK), U4.18 (SD_SCK), U7.26 (IO14/HSPI_CLK)
unnamed: U4.6 (SDI(MOSI)), U4.12 (T_DIN), U4.16 (SD_MOSI), U7.28 (IO13/HSPI_ID)
unnamed: U4.9 (SDO(MISO)), U4.13 (T_DO), U4.17 (SD_MISO), U7.27 (IO12/HSPI_Q)
unnamed: U4.11 (T_CS), U7.21 (IO32)
unnamed: U4.14 (T_IRQ_N), U7.20 (IO35)
unnamed: R1.1, SW1.5, U5.5 (OUT+), VBATT.1
unnamed: U6.1 (PPS), U7.8 (IO5)
unnamed: U6.6 (RESET_N), U7.9 (IO18)
unnamed: U6.4 (RXD), U7.7 (IO17/TX2)
unnamed: U6.3 (TXD), U7.6 (IO16/RX2)
unnamed: R1.2, R2.1, U7.10 (IO19)
SD_CS: U4.15 (SD_CS), U7.11 (IO21)
nSHDN: U3.2 (nSHDN), U7.22 (IO33)

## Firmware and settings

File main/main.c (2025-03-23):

/*
* SPDX-FileCopyrightText: 2010-2022 Espressif Systems (Shanghai) CO LTD
*
* SPDX-License-Identifier: CC0-1.0
*/

#include <stdio.h>
#include <inttypes.h>
#include "sdkconfig.h"
#include "freertos/FreeRTOS.h"
#include "freertos/task.h"
#include "esp_chip_info.h"
#include "esp_flash.h"
#include "esp_system.h"
#include "sht3x.h"

void app_main(void)
{
    printf("Hello world!\n");

    /* Print chip information */
    esp_chip_info_t chip_info;
    uint32_t flash_size;
    esp_chip_info(&chip_info);
    printf("This is %s chip with %d CPU core(s), %s%s%s%s, ",
        CONFIG_IDF_TARGET,
        chip_info.cores,
        (chip_info.features & CHIP_FEATURE_WIFI_BGN) ? "WiFi/" : "",
        (chip_info.features & CHIP_FEATURE_BT) ? "BT" : "",
        (chip_info.features & CHIP_FEATURE_BLE) ? "BLE" : "",
        (chip_info.features & CHIP_FEATURE_IEEE802154) ? ", 802.15.4 (Zigbee/Thread)" : "");

    unsigned major_rev = chip_info.revision / 100;
    unsigned minor_rev = chip_info.revision % 100;
    printf("silicon revision v%d.%d, ", major_rev, minor_rev);
    if(esp_flash_get_size(NULL, &flash_size) != ESP_OK) {
        printf("Get flash size failed");
        return;
    }

    printf("%" PRIu32 "MB %s flash\n", flash_size / (uint32_t)(1024 * 1024),
        (chip_info.features & CHIP_FEATURE_EMB_FLASH) ? "embedded" : "external");

    printf("Minimum free heap size: %" PRIu32 " bytes\n", esp_get_minimum_free_heap_size());

    for (int i = 10; i >= 0; i--) {
        printf("Restarting in %d seconds...\n", i);
        vTaskDelay(1000 / portTICK_PERIOD_MS);
    }
    printf("Restarting now.\n");
    fflush(stdout);
    esp_restart();
}

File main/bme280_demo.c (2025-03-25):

#include <stdio.h>
#include "bme280.h"
#include "i2c_bus.h"
#include "esp_log.h"
#include "freertos/FreeRTOS.h"
#include "freertos/task.h"

/*** 
 * This file is a quick-and-simple demonstration of using the 
 * espressif/bme280 component to read barometric pressure, temperature, 
 * and humidity and calculate altitude with a BME280 sensor and an 
 * ESP32. This initializes the I2C bus (espressif/i2c_bus) and the 
 * sensor object. My particular sensor board is configured to run with 
 * the default address of 0x76. Measurements for pressure, temperature 
 * and humidity are requested every 5 seconds until operation is 
 * interrupted. Altitude is also calculated every 5 seconds (it is not 
 * measured but rather calculated from a pressure measurement).
 * NOTE: I made several changes to the original component source code. 
 * Some were for debugging, but others were functional. There were bugs 
 * in the way pressure and altitude were calculated which have now been 
 * fixed. These fixes are present in the managed_components folder of 
 * this project.
*/

#define I2C_MASTER_PORT   I2C_NUM_0  // I2C port number
#define I2C_MASTER_SCL_IO 33         // GPIO pin for SCL
#define I2C_MASTER_SDA_IO 32         // GPIO pin for SDA
#define I2C_FREQ_HZ       100000     // I2C clock speed (Hz)
#define SEA_LEVEL_PRESS   1013.25f   // standard sea level pressure (hPa)

static const char *TAG = "BME280_DEMO";

void app_main(void)
{
    // measurements
    float temperature = 0;
    float pressure = 0;
    float humidity = 0; 
    float altitude = 0;

    // configure settings for I2C bus
    i2c_config_t i2c_conf = {
        .mode = I2C_MODE_MASTER,
        .sda_io_num = I2C_MASTER_SDA_IO,
        .sda_pullup_en = GPIO_PULLUP_ENABLE,
        .scl_io_num = I2C_MASTER_SCL_IO,
        .scl_pullup_en = GPIO_PULLUP_ENABLE,
        .master.clk_speed = I2C_FREQ_HZ,
    };

    // create I2C bus instance
    i2c_bus_handle_t i2c_bus = i2c_bus_create(I2C_MASTER_PORT, &i2c_conf);
    if (i2c_bus == NULL) 
    {
        ESP_LOGE(TAG, "Failed to initialize I2C bus! Terminating.");
        return;
    }
    else 
    {
        ESP_LOGI(TAG, "I2C bus initialized successfully!");
    }

    // instantiate BME280 sensor
    bme280_handle_t bme280 = bme280_create(i2c_bus, BME280_I2C_ADDRESS_DEFAULT);
    if (bme280 == NULL) 
    {
        ESP_LOGE(TAG, "Failed to create BME280 sensor! Terminating.");
        i2c_bus_delete(&i2c_bus);
        return;
    }
    else 
    {
        ESP_LOGI(TAG, "BME280 sensor created successfully!");
    }

    // initialize BME280 sensor
    if (bme280_default_init(bme280) != ESP_OK) 
    {
        ESP_LOGE(TAG, "Failed to initialize BME280 sensor! Terminating.");
        bme280_delete(&bme280);
        i2c_bus_delete(&i2c_bus);
        return;
    }
    else
    {
        ESP_LOGI(TAG, "BME280 sensor initialized successfully!");
    }

    /*** NOTE:  adding the delay here got rid of the issue where the first 
     * set of measurements taken below would always fail
    */
    vTaskDelay(500 / portTICK_PERIOD_MS);

    // infinite loop to read sensor data
    ESP_LOGI(TAG, "Starting infinite measurement loop...");    
    while (1) 
    {
        // read temperature
        if (bme280_read_temperature(bme280, &temperature) == ESP_OK) 
        {
            ESP_LOGI(TAG, "Temperature: %.2f °C", temperature);
        } 
        else 
        {
            ESP_LOGE(TAG, "Failed to read temperature!");
        }

        // read pressure
        if (bme280_read_pressure(bme280, &pressure) == ESP_OK) 
        {
            ESP_LOGI(TAG, "Pressure: %.2f hPa", pressure);
        } 
        else 
        {
            ESP_LOGE(TAG, "Failed to read pressure!");
        }

        // read humidity
        if (bme280_read_humidity(bme280, &humidity) == ESP_OK) 
        {
            ESP_LOGI(TAG, "Humidity: %.2f %%", humidity);
        } 
        else 
        {
            ESP_LOGE(TAG, "Failed to read humidity!");
        }

        // calculate altitude
        if (bme280_read_altitude(bme280, SEA_LEVEL_PRESS, &altitude) == ESP_OK) 
        {
            ESP_LOGI(TAG, "Altitude: %.2f meters", altitude);
        } 
        else 
        {
            ESP_LOGE(TAG, "Failed to calculate altitude!");
        }

        ESP_LOGI(TAG, "-----------------------------");
        
        // wait 5 seconds before taking the next measurement
        vTaskDelay(5000 / portTICK_PERIOD_MS);
    }

    // cleanup! this part is never reached due to the infinite loop.
    //bme280_delete(&bme280);
    //i2c_bus_delete(&i2c_bus);
}

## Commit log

2024-11-25 init commit - quick demo project for ESP IDF usage + empty KiCad projects for hardware designs
    [bike_computer.kicad_pcb, bike_computer.kicad_sch, rear_lights_unit.kicad_pcb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]
2024-12-04 added references for the LCD module and LEDs
2025-01-18 cleanup & gitignore updates for KiCad files
2025-03-18 schematic updates for bike computer, rear light unit, rear light unit control box
    [bike_computer.kicad_sch, rear_lights_unit.kicad_sch, rear_lights_unit_control_box.kicad_pcb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]
2025-03-23 migrated project to use pure esp-idf tools (no PlatformIO), added demo file for sht3x sensor, updated main readme
2025-03-23 added BMP280 pressure sensor demo draft
2025-03-23 more schematic updates
    [bike_computer.kicad_sch, rear_lights_unit.kicad_sch, rear_lights_unit_control_box.kicad_sch]
2025-03-24 adding the managed_components folder to the repo so that I can track my own changes to them
2025-03-24 modified debugging messages, fixed bugs in the way pressure and altitude were calculated, removed unused humidity measurement function
2025-03-26 finalized rear light unit schematic, added corresponding BOM
    [rear_lights_unit.kicad_sch, rear_lights_unit_BOM.csv]
2025-03-26 finalized rear light unit control box schematic, added corresponding BOM
    [rear_lights_unit_control_box.kicad_sch, rear_lights_unit_control_box_BOM.csv]
2025-03-27 rear light control box: added test points to I/O signals, improved BOM (added specific part numbers, descriptions, etc), started PCB layout. started project footprint file, fixed error in TP4056 symb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
    [rear_lights_unit_control_box.kicad_pcb, rear_lights_unit_control_box.kicad_sch, rear_lights_unit_control_box_BOM.csv]
2025-03-27 rear light unit control box: finished first draft of PCB
    [rear_lights_unit_control_box-B_Cu.gbr, rear_lights_unit_control_box-B_Mask.gbr, rear_lights_unit_control_box-B_Silkscreen.gbr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]
2025-03-28 fixed page size for rear light control box PCB so I can print to scale, regenerated related files
    [rear_lights_unit_control_box-B_Cu.gbr, rear_lights_unit_control_box-B_Mask.gbr, rear_lights_unit_control_box-B_Silkscreen.gbr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]
2025-03-28 rear light unit: finished first draft of PCB, regenerated all related files
    [rear_lights_unit-B_Cu.gbr, rear_lights_unit-B_Mask.gbr, rear_lights_unit-B_Silkscreen.gbr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]
2025-03-29 completed footprint for LCD breakout board
2025-03-30 added footprint for RYS352A GNSS module
2025-03-31 modified TP4056 dimensions, fixed typo in footprint file name
2025-03-31 cleaned up managed_components folder and specified which sensors are not actually being used
2025-03-31 added footprint for BME280 module, made some small changes to LCD and GNSS module symbols
2025-03-31 added new footprint and symbol for my ESP32 dev module (previous ones were for a slightly different module)
2025-03-31 more schematic updates: re-did bike computer with better ESP32 symbol, fixed component data on other schematics (somehow some of the part nums, descriptions, etc disappeared??)
    [bike_computer.kicad_pcb, bike_computer.kicad_sch, bike_computer_BOM.csv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]
2025-03-31 added more dev env details to main readme, added symbol/footprint for power switch and 5-pin TO-220
2025-04-01 rear light unit control box PCB finalized!
    [rear_lights_unit_control_box-B_Cu.gbr, rear_lights_unit_control_box-B_Fab.gbr, rear_lights_unit_control_box-B_Mask.gbr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]
2025-04-01 finalized rear light unit v0
    [rear_lights_unit-B_Cu.gbr, rear_lights_unit-B_Fab.gbr, rear_lights_unit-B_Mask.gbr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]
2025-04-04 fixed naming typo, added 3D models for TP4056, ESP32, and BME280 modules
    [BME280_SENSOR_MODULE_WITH_HEADER.STEP]
2025-04-04 bike computer layout v0
    [bike_computer-B_Cu.gbr, bike_computer-B_Fab.gbr, bike_computer-B_Mask.gbr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]
2025-04-04 updated both sets of light unit board files to include the newly-added 3D models
    [rear_lights_unit.kicad_pcb, rear_lights_unit.kicad_sch, rear_lights_unit_BOM.csv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]
